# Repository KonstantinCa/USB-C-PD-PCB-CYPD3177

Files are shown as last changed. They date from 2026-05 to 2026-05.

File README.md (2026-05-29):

# USB-C Power Delivery PCB

**Note:** This project was developed as part of a university project. Technical references and documentation from the relevant companies/manufacturers, especially Infineon/Cypress documentation for the CYPD3177 USB-PD controller, were used as supporting sources for the design and analysis. The project is for educational and documentation purposes only.

This project focuses on the design and analysis of a USB-C Power Delivery sink system.  
The goal was to develop a custom PCB capable of requesting defined USB-PD voltage profiles from a USB-C Power Delivery charger.

The system is based on the Infineon/Cypress CYPD3177 USB-PD controller.  
An external microcontroller communicates with the controller via I2C in order to select different Power Delivery profiles and read status information such as the negotiated VBUS voltage.

## Project Overview

The project combines hardware design, embedded firmware and protocol analysis.  
The custom PCB was designed in KiCad and includes the required USB-C connector, USB-PD controller, power path circuitry, voltage regulation and communication interfaces.

## Features

- USB-C Power Delivery sink implementation
- CYPD3177 USB-PD controller integration
- Selection of different USB-PD voltage profiles
- I2C communication between microcontroller and USB-PD controller
- VBUS voltage measurement
- Interrupt-based response handling
- Finite State Machine firmware structure
- KiCad schematic and PCB layout
- Analysis of USB-PD, USB 2.0, I2C and UART communication

## Supported USB-PD Profiles

The firmware supports the following fixed supply PDO profiles:

| Profile | Voltage | Current |
|---|---:|---:|
| 1 | 5 V | 2 A |
| 2 | 9 V | 2 A |
| 3 | 12 V | 2.25 A |
| 4 | 15 V | 1.8 A |
| 5 | 20 V | 1.5 A |

## Firmware

The ESP32 firmware communicates with the CYPD3177 over I2C and allows the user to select a desired USB-PD profile via the serial monitor.

### Serial Commands

| Command | Function |
|---|---|
| `STATUS` | Reads the current status and response information |
| `5V2A` | Requests 5 V / 2 A |
| `9V2A` | Requests 9 V / 2 A |
| `12V2.25A` | Requests 12 V / 2.25 A |
| `15V1.8A` | Requests 15 V / 1.8 A |
| `20V1.5A` | Requests 20 V / 1.5 A |

### Firmware State Machine

The firmware is structured as a finite state machine:

```text
INIT -> IDLE -> SEND -> WAIT -> RECEIVE -> IDLE

The state machine waits for user input, checks whether a USB-PD contract is established, sends the selected PDO to the CYPD3177, waits for an interrupt, and then reads the response and VBUS voltage.

## Hardware Design

The PCB design contains the following main functional blocks:

- USB-C connector
- CYPD3177 USB Power Delivery controller
- Power path switching stage
- Buck converter for 3.3 V supply generation
- USB-to-UART interface for communication and debugging
- Microcontroller interface
- I2C communication lines
- UART communication lines
- Protection and configuration circuitry

The PCB was designed as a four-layer board with separate layers for signal routing, ground reference, and power distribution.

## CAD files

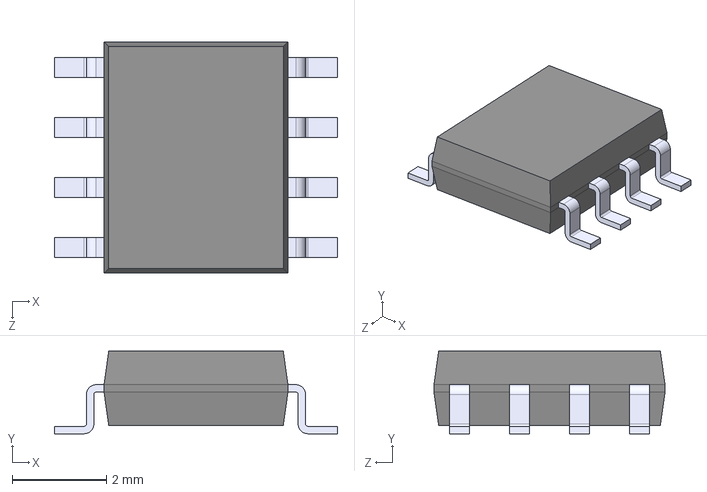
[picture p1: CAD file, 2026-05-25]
USB-C_PD_PCB/3D-Modelle/IRF9362TRPBF.step
6.00 x 1.75 x 4.90 mm

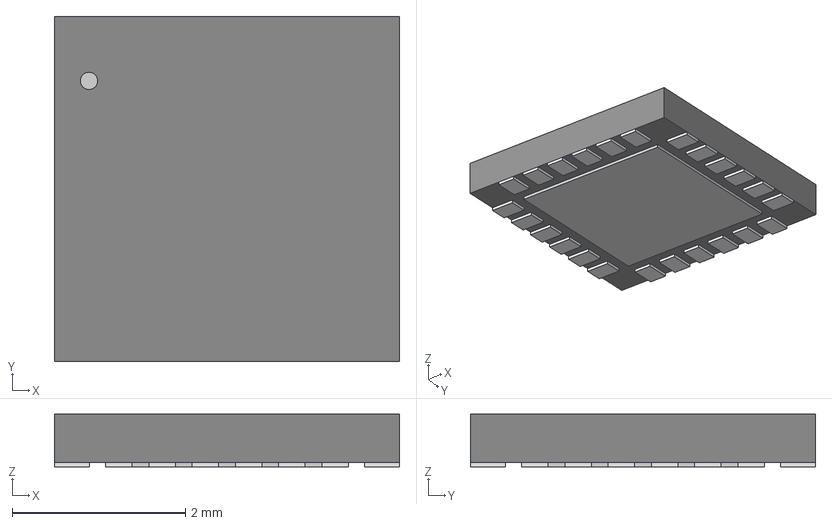
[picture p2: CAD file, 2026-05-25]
USB-C_PD_PCB/Bib/CYPD3177_24LQXQ/KiCADv6/QFN24_CYPD3177_INF.step
3.99 x 3.99 x 0.612 mm

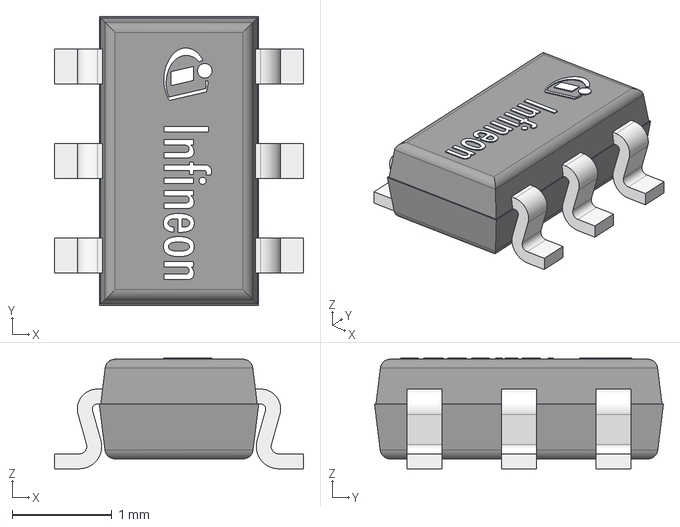
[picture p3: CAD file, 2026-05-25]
USB-C_PD_PCB/Bib/ul_BSL308PEH6327XTSA1/PG-TSOP6-6-6.stp
2.50 x 2.90 x 1.11 mm

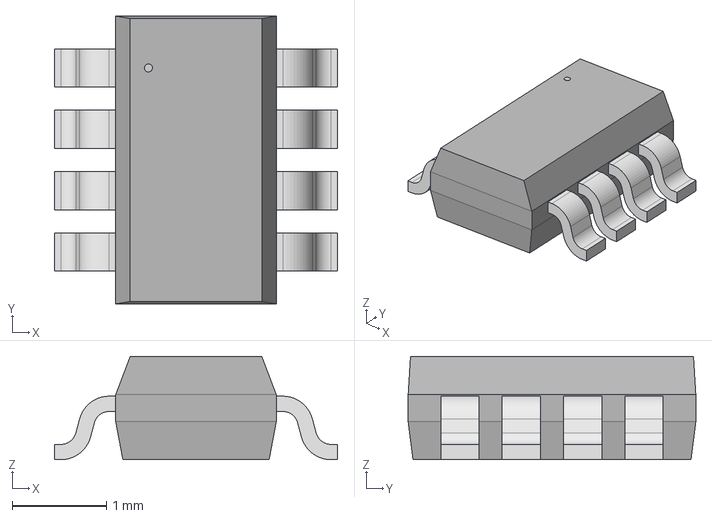
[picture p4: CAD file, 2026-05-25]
USB-C_PD_PCB/Bib/ul_SY8303AIC (2)/TSOT_303AIC_SGY.step
3.00 x 3.05 x 1.09 mm

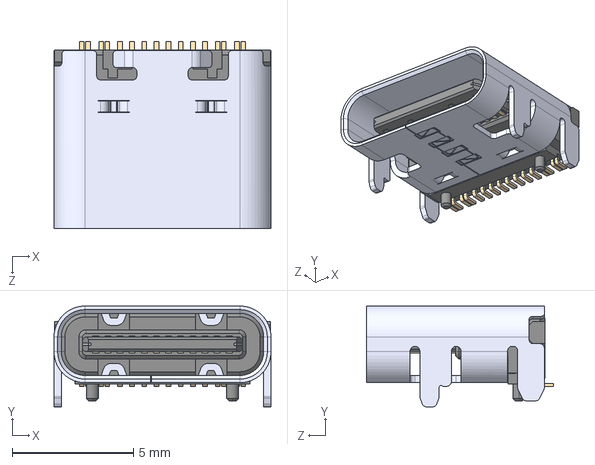
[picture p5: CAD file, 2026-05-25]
USB-C_PD_PCB/Bib/USB4105_GF_A_060/USB4105-GF-A-060.step
8.94 x 4.16 x 7.71 mm

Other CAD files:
USB-C_PD_PCB/Bib/CYPD3177_24LQXQ/KiCADv6/QFN24_CYPD3177_INF.stl

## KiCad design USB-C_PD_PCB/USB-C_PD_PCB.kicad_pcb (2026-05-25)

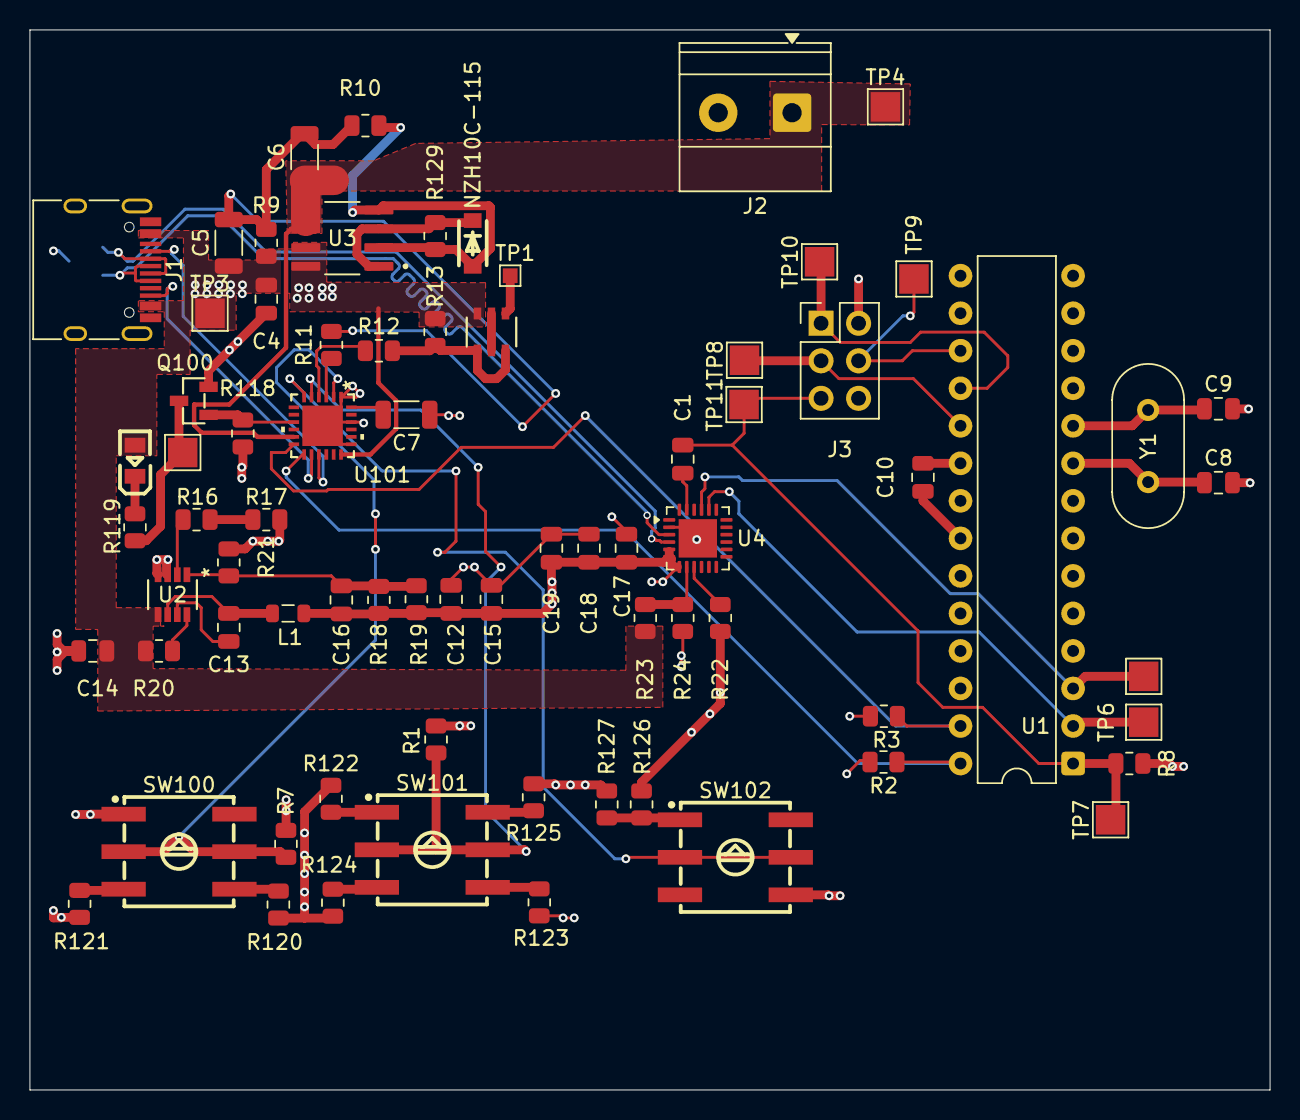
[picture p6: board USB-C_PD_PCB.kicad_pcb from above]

Board: 4 copper layers, 83.9 x 71.8 mm, 75 parts (1 on the bottom side), 49 nets.

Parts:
BSL308PEH6327XTSA1: BSL308PEH6327XTSA1; PG-TSOP6-6-4_INF
C1: 4.7uF; C_0805_2012Metric
C4: 3.3uF; C_0805_2012Metric
C5, C6: 1uF; L_1206_3216Metric
C7: 100nF; L_1206_3216Metric
C8, C9: 22pF; C_0805_2012Metric
C10: ´10uF; C_0805_2012Metric
C12, C14, C15: 4u7; C_0805_2012Metric
C13: 100n; C_0805_2012Metric
C16: 10p; C_0805_2012Metric
C17, C18, C19: 100nF; C_0805_2012Metric
D1: ESDA5V3L; SOT-23-3
D101: LED PD; LED0805-R-RD
J1: USB4105-GF-A-060; USB_C_Receptacle_HRO_TYPE-C-31-M-12
J2: Screw_Terminal_01x02; TerminalBlock_Phoenix_MKDS-1,5-2_1x02_P5.00mm_Horizontal
J3: AVR-ISP-6; PinHeader_2x03_P2.54mm_Vertical
L1: 47u; L_0805_2012Metric
NZH10C-115: Zener Diode; SOD-123F_L2.8-W1.8-LS3.7-RD
Q100: NTR4503N; NTR4503NT1G-VB
R1, R7: 5k1; R_0805_2012Metric
R2, R3, R119: 1K; R_0805_2012Metric
R8, R11, R12, R22, R120: 1k; R_0805_2012Metric
R9: 10k; R_0805_2012Metric
R10: 0R; R_0805_2012Metric
R13: 49.9k; R_0805_2012Metric
R16, R17: 100k; R_0805_2012Metric
R18, R19: 2M; R_0805_2012Metric
R20: 20k; R_0805_2012Metric
R21: 222K; R_0805_2012Metric
R23: 180k; R_0805_2012Metric
R24: 33K; R_0805_2012Metric
R118: 100K 5%; R_0805_2012Metric
R121: 2.4k; R_0805_2012Metric
R122: 1 k; R_0805_2012Metric
R123, R127: 2.4 k; R_0805_2012Metric
R124, R126: 5.1 k; R_0805_2012Metric
R125: 10 k; R_0805_2012Metric
R129: 49.9K; R_0805_2012Metric
SW100: VBUS_Max; SW-SMD_MSSR-10S
SW101: Sink_Coarse; SW-SMD_MSSR-10S
SW102: Sink_fine; SW-SMD_MSSR-10S
TP1: TestPoint 5V; TestPoint_Pad_1.0x1.0mm
TP2, TP3, TP4, TP5, TP6, TP7, TP8, TP9, TP10, TP11: TestPoint; TestPoint_Pad_2.0x2.0mm
U1: ATmega328-P; DIP-28_W7.62mm
U2: SY8303AIC; TSOT_303AIC_SGY
U3: IRF9362TRPBF; SOIC127P600X175-8N
U4: CP2102N-Axx-xQFN24; QFN-24-1EP_4x4mm_P0.5mm_EP2.6x2.6mm
U101: CYPD3177-24LQXQT; QFN24_CYPD3177_INF
Y1: 8MHz; Crystal_HC49-U_Vertical

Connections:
+3.3V: C12.1, C15.1, C16.1, C17.1, C18.1, C19.1, J3.2 (VCC), L1.2, R1.1, R2.2, R3.2, R7.1, R8.2, R18.1, R19.1, R22.1, R126.1, U1.7 (VCC), U4.5 (VIO), U4.6 (VDD), U4.7 (VREGIN)
/GATE: NZH10C-115.2 (A), R10.1, R129.2, U3.2 (G1), U3.4 (G2)
/R_I_1A: R122.1, SW101.1
/R_I_2A: R123.1, SW101.2
/R_I_3A: R124.1, SW101.4
/R_I_4A: R125.1, SW101.8
/R_I_+500mA: R126.2, R127.1, SW102.1
/R_V_9V: R120.1, SW100.2
/R_V_12V: R121.1, SW100.4
/SOURCE: NZH10C-115.1 (K), R129.1, U3.1 (S1), U3.3 (S2)
CC1: J1.A5 (CC1), U101.15 (CC1)
CC2: J1.B5 (CC2), U101.14 (CC2)
D+: D1.2 (K), J1.A6 (DP1), J1.B6 (DP2), U4.3 (D+)
D-: D1.1 (K), J1.A7 (DN1), J1.B7 (DN2), U4.4 (D-)
GND: C4.1, C7.1, C8.2, C9.2, C10.2, C12.2, C14.2, C15.2, C17.2, C18.2, C19.2, D1.3 (A), J1.A1, J1.A12, J1.B1, J1.B12, J1.S1, J2.2, J3.6 (GND), Q100.2 (S), R17.1, R21.1, R24.2, R118.2, R120.2, R121.2, R122.2, R123.2, R124.2, R125.2, R127.2, SW100.1, SW102.2, U1.8 (GND), U1.22 (GND), U2.3 (GND), U2.4 (GND), U4.2 (GND), U4.25 (GND), U101.1 (VBUS_MIN), U101.19 (GND), U101.22 (VSS), U101.25 (EPAD)
ISNK_COARSE: R1.2, SW101.C, U101.5 (ISNK_COARSE)
ISNK_FINE: SW102.C, U101.6 (ISNK_FINE)
MISO: J3.1 (MISO), TP10.1, U1.18 (PB4)
MOSI: J3.4 (MOSI), TP9.1, U1.17 (PB3)
unnamed: BSL308PEH6327XTSA1.1, BSL308PEH6327XTSA1.3, R12.2, R13.1
unnamed: BSL308PEH6327XTSA1.2, BSL308PEH6327XTSA1.5
unnamed: BSL308PEH6327XTSA1.4, TP1.1
unnamed: C5.2, C6.2, R9.2, R10.2, R11.1
unnamed: D101.2 (K), R119.1
unnamed: Q100.3 (D), R119.2, TP2.1
unnamed: Q100.1 (G), R118.1, U101.9 (FAULT)
unnamed: R16.1, R17.2
unnamed: C10.1, U1.20 (AVCC)
unnamed: C8.1, U1.9 (XTAL1/PB6), Y1.1
unnamed: C9.1, U1.10 (XTAL2/PB7), Y1.2
unnamed: C13.1, U2.7 (BS)
unnamed: R20.2, U2.8 (EN)
unnamed: C16.2, R18.2, R19.2, R21.2, U2.1 (FB)
unnamed: R16.2, U2.2 (FS)
unnamed: C13.2, L1.1, U2.6 (LX)
unnamed: R23.2, R24.1, U4.8 (VBUS)
unnamed: R22.2, U4.9 (~RST)
unnamed: R11.2, U101.3 (VBUS_FET_EN)
unnamed: C7.2, U101.24 (VCCD)
RESET_uC: C1.2, J3.5 (~RST), R8.1, TP7.1, TP11.1, U1.1 (~RESET/PC6)
RXD_uC: TP5.1, U1.3 (PD1), U4.20 (RXD)
SAVE_PWR_EN: R12.1, U101.4 (SAFE_PWR_EN)
SCK: J3.3 (SCK), TP8.1, U1.19 (PB5)
SCL: R2.1, U1.28 (PC5), U101.13 (HPI_SCL)
SDA: R3.1, U1.27 (PC4), U101.12 (HPI_SDA)
TXD_uC: TP6.1, U1.2 (PD0), U4.21 (TXD)
VBUS_IN: BSL308PEH6327XTSA1.6, C4.2, C5.1, C14.1, D101.1 (A), J1.A4, J1.A9, J1.B4, J1.B9, R9.1, R13.2, R20.1, R23.1, TP3.1, U2.5 (IN), U3.7 (D1_2), U3.8 (D1), U101.18 (VBUS_IN)
VBUS_MAX: R7.2, SW100.C, U101.2 (VBUS_MAX)
VBUS_OUT: C6.1, J2.1, TP4.1, U3.5 (D2_2), U3.6 (D2), U101.11 (VDC_OUT)

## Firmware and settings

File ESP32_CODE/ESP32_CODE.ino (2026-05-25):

// -----------------------------------------------------------------------------
// Finite State Machine (FSM) zur Steuerung der USB-PD-Kommunikation
// INIT -> IDLE -> SENDEN -> WAIT -> EMPFANGEN -> IDLE
// -----------------------------------------------------------------------------

// Interrupt-Pin des CYPD3177 (aktiv LOW)
#define CYPD_INT_PIN 43

#include <Wire.h>   // I2C-Kommunikation
#include <math.h>   // NAN für Fehlerfälle bei Messwerten

// I2C-Adresse des CYPD3177
#define CYPD3177_I2C_ADDR 0x08

// I2C-Pins des ESP32
#define SDA_PIN 15
#define SCL_PIN 7

// Index für das ausgewählte PDO
size_t i = 0;

// Gemessene VBUS-Spannung
float v = 0.0;

// Wichtige Register- und Kommandoadressen des CYPD3177
#define CYPD_PD_STATUS_REG          0x1008
#define CYPD_DATA_MEMORY_START_ADDR 0x1800
#define CYPD_SELECT_SINK_PDO_CMD    0x1005
#define CYPD_PD_RESPONSE_CMD        0x1400

// Definition der FSM-Zustände
enum State {
  INIT,
  IDLE,
  SENDEN,
  WAIT,
  EMPFANGEN
};

// Unterstützte Sink-PDOs (Fixed Supply PDOs, USB-PD-konform codiert)
const uint32_t pdos[] = {
  0x000190C8,  // 5 V, 2 A
  0x0002D0C8,  // 9 V, 2 A
  0x0003C0E1,  // 12 V, 2.25 A
  0x0004B0B4,  // 15 V, 1.8 A
  0x00064064   // 20 V, 1.5 A
};

// Klartext-Ausgabe für serielle Konsole
String text[] = {
  "5V, 2A",
  "9V, 2A",
  "12V, 2.25A",
  "15V, 1.8A",
  "20V, 1.5A"
};

// Aktueller und vorheriger FSM-Zustand
State state = INIT;
State lastState = INIT;

// Steuer-Flags
bool cmdReceived = false;   // Serielle Eingabe empfangen
bool txDone = false;        // PDO erfolgreich gesendet
bool dataReady = false;     // Reserviert (nicht aktiv genutzt)
bool errorFlag = false;     // Fehlerstatus

// Funktionsprototypen
bool checkPDStatus();
void selectPDO(uint32_t PDO);
float readVbusVoltage_V();
bool waitIntrAndReadResponses(uint32_t timeoutMs,
                              uint8_t *intrStatus,
                              uint8_t pdResp[4],
                              uint8_t devResp[2]);

// -----------------------------------------------------------------------------
// Initialisierung
// -----------------------------------------------------------------------------
void setup() {
  pinMode(CYPD_INT_PIN, INPUT_PULLUP); // INT# ist aktiv LOW

  Wire.begin(SDA_PIN, SCL_PIN);        // I2C initialisieren
  Serial.begin(115200);                // Serielle Konsole
  delay(1000);

  Serial.println("Setup Complete");
  state = INIT;
}

// -----------------------------------------------------------------------------
// Hauptschleife mit FSM
// -----------------------------------------------------------------------------
void loop() {

  // Zustandswechsel debuggen
  if (state != lastState) {
    Serial.print("STATE -> ");
    switch (state) {
      case INIT: Serial.println("INIT"); break;
      case IDLE: Serial.println("IDLE"); break;
      case SENDEN: Serial.println("SENDEN"); break;
      case WAIT: Serial.println("WAIT"); break;
      case EMPFANGEN: Serial.println("EMPFANGEN"); break;
    }
    lastState = state;
  }

  switch (state) {

    // -------------------------------------------------------------------------
    // INIT: Rücksetzen aller Status-Flags
    // -------------------------------------------------------------------------
    case INIT:
      cmdReceived = false;
      txDone = false;
      dataReady = false;
      errorFlag = false;
      state = IDLE;
      break;

    // -------------------------------------------------------------------------
    // IDLE: Warten auf serielle Benutzereingabe
    // -------------------------------------------------------------------------
    case IDLE:
      if (!Serial.available()) {
        delay(10);
        break;
      }
      cmdReceived = true;
      state = SENDEN;
      break;

    // -------------------------------------------------------------------------
    // SENDEN: Kommando auswerten und ggf. PDO senden
    // -------------------------------------------------------------------------
    case SENDEN: {
      if (!cmdReceived) {
        state = IDLE;
        break;
      }
      cmdReceived = false;

      // Prüfen, ob bereits ein PD-Vertrag besteht
      if (!checkPDStatus()) {
        Serial.println("PD Status does not indicate an established contract.");
        state = IDLE;
        break;
      }

      Serial.println("PD established contract.");

      // Kommando einlesen
      String cmd = Serial.readStringUntil('\n');
      cmd.trim();
      txDone = false;

      // STATUS-Kommando: nur Antworten auslesen
      if (cmd == "STATUS") {
        state = EMPFANGEN;
        break;
      }
      // PDO-Auswahl
      else if (cmd == "5V2A")        { i = 0; txDone = true; }
      else if (cmd == "9V2A")        { i = 1; txDone = true; }
      else if (cmd == "12V2.25A")    { i = 2; txDone = true; }
      else if (cmd == "15V1.8A")     { i = 3; txDone = true; }
      else if (cmd == "20V1.5A")     { i = 4; txDone = true; }
      else {
        Serial.println("Ungueltiges Kommando");
        state = IDLE;
        break;
      }

      // PDO an CYPD3177 übertragen
      Serial.println("Voltage: " + text[i]);
      selectPDO(pdos[i]);

      state = WAIT;
      break;
    }

    // -------------------------------------------------------------------------
    // WAIT: Warten auf Interrupt des CYPD3177
    // -------------------------------------------------------------------------
    case WAIT:
      if (digitalRead(CYPD_INT_PIN) == LOW) {
        state = EMPFANGEN;
      }
      break;

    // -------------------------------------------------------------------------
    // EMPFANGEN: Interrupt-Status und Responses auslesen
    // -------------------------------------------------------------------------
    case EMPFANGEN: {
      uint8_t intr = 0;
      uint8_t pd[4];
      uint8_t dev[2];

      // Warten auf INT# und Auslesen der Response-Register
      if (!waitIntrAndReadResponses(500, &intr, pd, dev)) {
        Serial.println("INTR timeout");
        state = IDLE;
        break;
      }

      Serial.print("INTERRUPT=0x");
      Serial.println(intr, HEX);

      // VBUS-Spannung nach kurzer Stabilisierung messen
      delay(400);
      v = readVbusVoltage_V();

      if (!isnan(v)) {
        Serial.print("VBUS = ");
        Serial.print(v, 1);
        Serial.println(" V");
      }

      state = IDLE;
      break;
    }
  }
}
bool checkPDStatus() {
  uint8_t status[4];

  Wire.beginTransmission(CYPD3177_I2C_ADDR);
  Wire.write(CYPD_PD_STATUS_REG & 0xFF);
  Wire.write((CYPD_PD_STATUS_REG >> 8) & 0xFF);
  Wire.endTransmission();

  if (Wire.requestFrom(CYPD3177_I2C_ADDR, 4) != 4) {
    Serial.println("Error: Could not read the complete PD status.");
    return false;
  }

  status[0] = Wire.read();
  status[1] = Wire.read();
  status[2] = Wire.read();
  status[3] = Wire.read();

  // Check if status is 00 A4 05 00
  return (status[0] == 0x00 && status[1] == 0xA4 && status[2] == 0x05 && status[3] == 0x00);
}

void selectPDO(uint32_t PDO) {
  const uint8_t snkp[4] = { 0x50, 0x4B, 0x4E, 0x53 };

  Wire.beginTransmission(CYPD3177_I2C_ADDR);
  Wire.write(CYPD_DATA_MEMORY_START_ADDR & 0xFF);
  Wire.write((CYPD_DATA_MEMORY_START_ADDR >> 8) & 0xFF);

  Wire.write(snkp, 4);

  uint32_t onepdo[] = { PDO };
  for (int k = 0; k < 7; k++) {
    if (k < (int)(sizeof(onepdo) / sizeof(onepdo[0]))) {
      Wire.write((uint8_t*)&onepdo[k], 4);
    } else {
      Wire.write(0x00); Wire.write(0x00); Wire.write(0x00); Wire.write(0x00);
    }
  }

  Wire.endTransmission();

  Wire.beginTransmission(CYPD3177_I2C_ADDR);
  Wire.write(CYPD_SELECT_SINK_PDO_CMD & 0xFF);
  Wire.write((CYPD_SELECT_SINK_PDO_CMD >> 8) & 0xFF);
  Wire.write(1);
  Wire.endTransmission();
}

float readVbusVoltage_V() {
  const uint16_t BUS_VOLTAGE_REG = 0x100D;

  Wire.beginTransmission(CYPD3177_I2C_ADDR);
  Wire.write(BUS_VOLTAGE_REG & 0xFF);
  Wire.write((BUS_VOLTAGE_REG >> 8) & 0xFF);

  if (Wire.endTransmission(false) != 0) {
    return NAN;
  }

  if (Wire.requestFrom(CYPD3177_I2C_ADDR, (uint8_t)1) != 1) {
    return NAN;
  }

  uint8_t raw = Wire.read();
  return raw * 0.1f;  // 100 mV Schritte -> Volt
}

bool waitIntrAndReadResponses(uint32_t timeoutMs,
                              uint8_t *intrStatus,
                              uint8_t pdResp[4],
                              uint8_t devResp[2]) {
  const uint16_t REG_INTERRUPT    = 0x0006; // R/W1C
  const uint16_t REG_DEV_RESPONSE = 0x007E; // 2 bytes
  const uint16_t REG_PD_RESPONSE  = 0x1400; // 4 bytes

  auto readBytes = [&](uint16_t reg, uint8_t *buf, uint8_t len) -> bool {
    Wire.beginTransmission(CYPD3177_I2C_ADDR);
    Wire.write((uint8_t)(reg & 0xFF));
    Wire.write((uint8_t)((reg >> 8) & 0xFF));
    if (Wire.endTransmission(false) != 0) return false;
    if (Wire.requestFrom(CYPD3177_I2C_ADDR, len) != len) return false;
    for (uint8_t i = 0; i < len; i++) buf[i] = Wire.read();
    return true;
  };

  auto write8 = [&](uint16_t reg, uint8_t val) -> bool {
    Wire.beginTransmission(CYPD3177_I2C_ADDR);
    Wire.write((uint8_t)(reg & 0xFF));
    Wire.write((uint8_t)((reg >> 8) & 0xFF));
    Wire.write(val);
    return (Wire.endTransmission(true) == 0);
  };

  // 1) Auf INTR# warten (aktiv LOW)
  uint32_t t0 = millis();
  while (digitalRead(CYPD_INT_PIN) != LOW) {
    if (timeoutMs && (millis() - t0 >= timeoutMs)) return false;
    delay(1);
  }

  // 2) INTERRUPT lesen
  uint8_t intr = 0;
  if (!readBytes(REG_INTERRUPT, &intr, 1)) return false;
  if (intrStatus) *intrStatus = intr;

  if (pdResp)  for (int i = 0; i < 4; i++) pdResp[i] = 0;
  if (devResp) for (int i = 0; i < 2; i++) devResp[i] = 0;

  bool anyRead = false;

  if ((intr & 0x01) && devResp) {
    if (!readBytes(REG_DEV_RESPONSE, devResp, 2)) return false;
    anyRead = true;
  }

  if ((intr & 0x02) && pdResp) {
    if (!readBytes(REG_PD_RESPONSE, pdResp, 4)) return false;
    anyRead = true;
  }

  // 3) W1C quittieren
  uint8_t clearMask = intr & 0x03;
  if (clearMask) {
    if (!write8(REG_INTERRUPT, clearMask)) return false;
  }

  return anyRead;
}

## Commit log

2026-05-25 Add ESP32 firmware
2026-05-25 Add KiCad PCB design files
    [IRF9362TRPBF.step, PG-TSOP6-6-6.stp, QFN24_CYPD3177_INF.step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]
